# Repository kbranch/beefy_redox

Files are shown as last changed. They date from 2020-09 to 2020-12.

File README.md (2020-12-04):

# Beefy Redox
This uses the Redox layout with significant modifications to make it feel and sound sturdy.  It's dumb and overkill, but I like it.  PCB has been redone to work with Kailh MX hotswap sockets because Mill-Max sockets don't really fit some switches (like Kailh's box series).

Based on Mattia Dal Ben's Redox keyboard: https://github.com/mattdibi/redox-keyboard

Case based on Fosk_LL's design: https://www.thingiverse.com/thing:3607303

Associated hacked together firmware: https://github.com/kbranch/qmk_beefy_redox

Disasterous CAD files are available here:
https://cad.onshape.com/documents/79753b5942c6535c2d806763/w/4c8392e04a1d78f77636699a/e/d620deb7dfbc2bdc09fda4c7
https://cad.onshape.com/documents/7a9b7e869b26a13f2521e861/w/94ad519ba1de32380f27d44b/e/4a5e31582eda700c8368bdb9

## Printing

The STLs folder here on GitHub should include everything you need.  Some portions of the case are symmetrical, while others are not.  If there is no "Right" version of a model that has a "Left" version, use your slicer to mirror the left version to create the right version.

I used PrusaSlicer with my non-MMU printer to print the little LED diffuser bits in white by setting it up to let me manually change the filament at the right time, but you can also print the diffusers separately and install them after the fact.  The STLs folder has the separate plug as well as individual models suitable for importing as part of a multi-material file.

## Assembly

This is designed to use a separate plate for the switches - the "Redox_Plate.dxf" file should be suitable for sending to a company to be laser cut, although you will likely need to drill the M2 holes out to size.  I found stainless steel to sound best, but any other 1.5 mm thick material should also work.  The plate can be attached to the case with six M2 screws. I found that the sound improved when I offset the plate from the case with a little o-ring around each screw, but that's optional.

The case halves are designed to be held together with M3 screws.  There are pockets for M3 nuts - you may need to glue the nuts in place, the pockets are tricky to print well.

Note that the footprint for the microcontroller is wider than a Pro Micro due to PCB space limitations after turning the switch footprint into swiss cheese.  I floated a header off to the side of my Pro Micros with a bunch of fine wire to make it fit.

This uses four panel mount USB-C connectors - one for each controller, and one on each side for the connection between the two halves.  I used these, but there may be other places to get some with the same dimensions: https://www.adafruit.com/product/4053

The LED PCB uses these LEDs, 9 per side: https://www.adafruit.com/product/3484

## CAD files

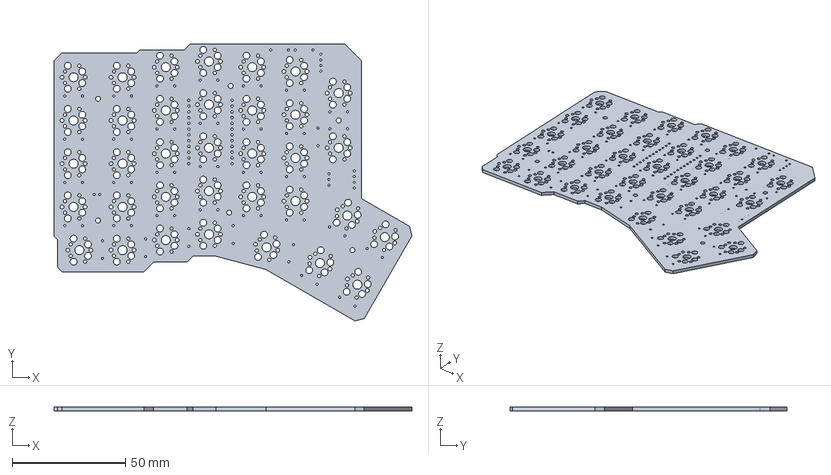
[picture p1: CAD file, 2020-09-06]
kicad_files/redox_rev1.1-kb.step
157.8 x 122.0 x 1.60 mm

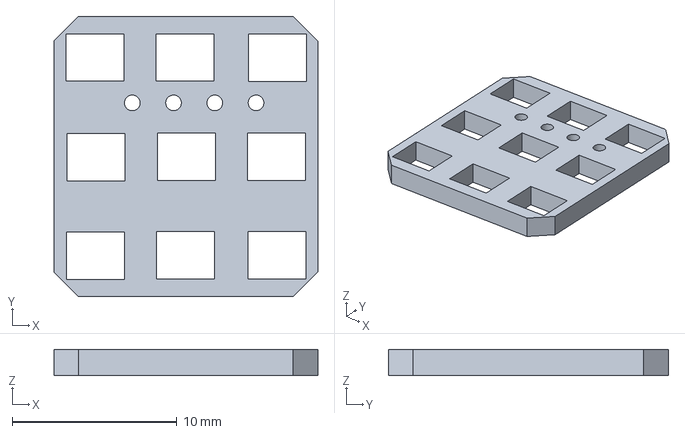
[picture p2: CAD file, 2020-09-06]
kicad_files/status_leds/status_leds/status_leds.step
16.0 x 17.0 x 1.60 mm

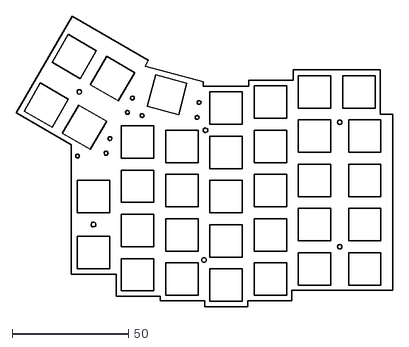
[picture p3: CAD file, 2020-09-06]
Redox_Plate.dxf
161.9 x 125.0

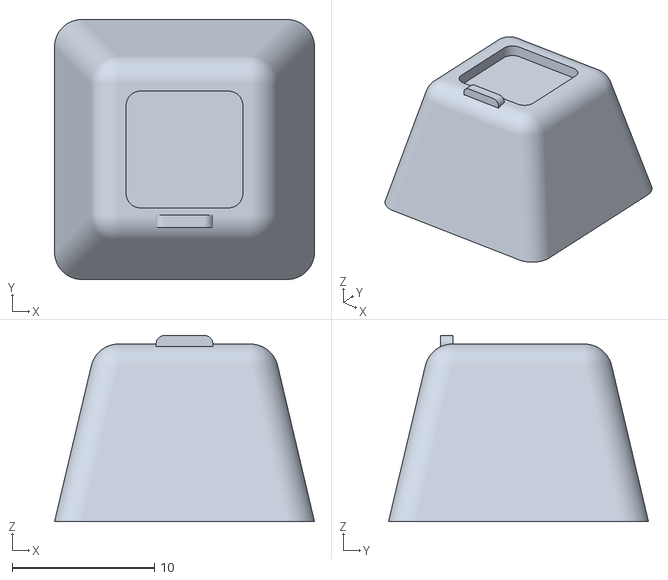
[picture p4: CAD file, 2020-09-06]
STLs/Keycaps/Keycap - 1U R3 Bump.stl
18.3 x 18.3 x 13.1

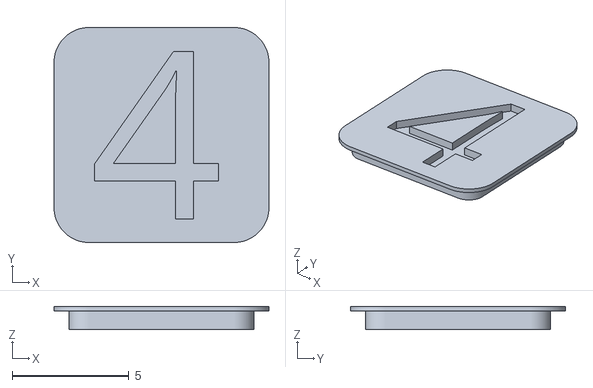
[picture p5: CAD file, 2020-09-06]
STLs/Keycaps/Legends/Keycap - Legend Block - 4.stl
9.21 x 9.21 x 1.00

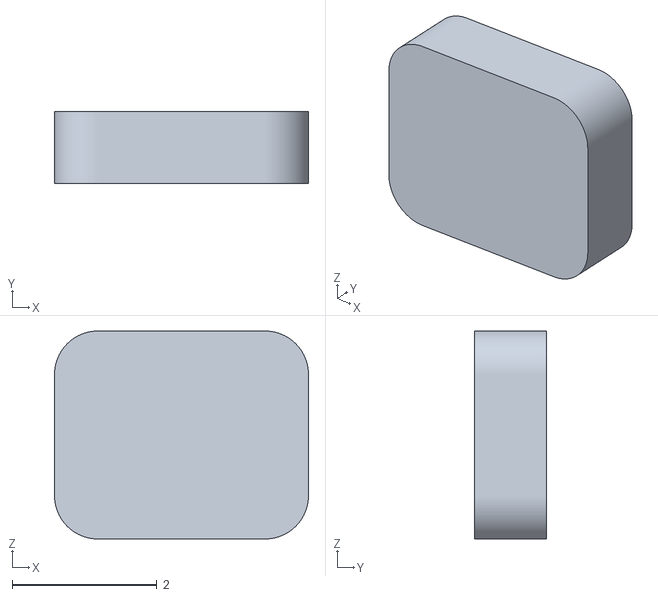
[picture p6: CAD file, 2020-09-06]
STLs/Left Top (mirror for right)/Integrated LED Plug 6.stl
3.51 x 1.00 x 2.87

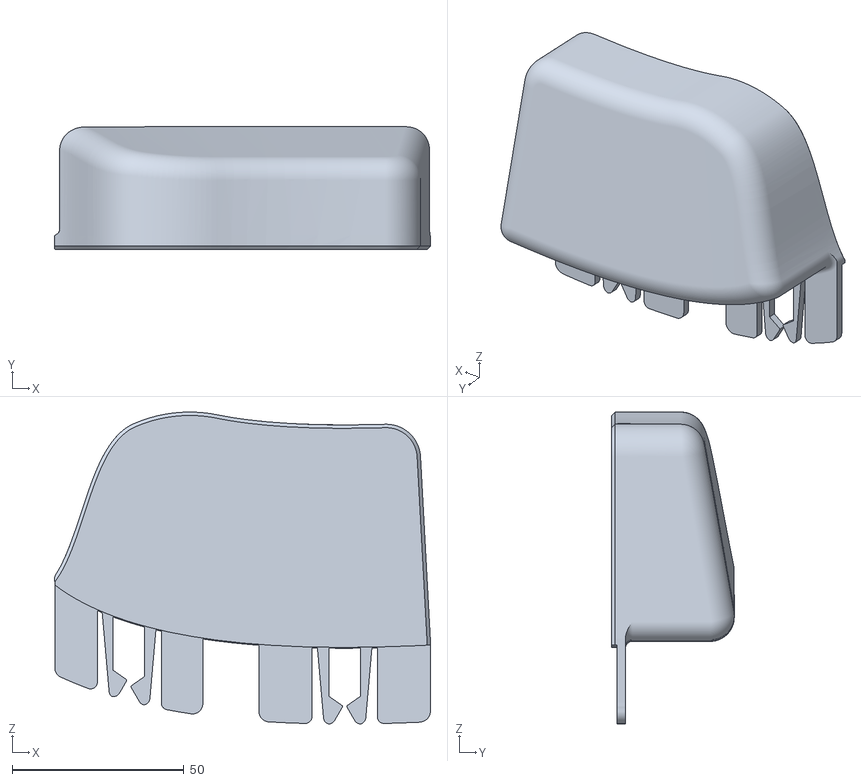
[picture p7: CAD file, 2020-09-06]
STLs/Right Wrist Rest.stl
109.4 x 35.7 x 90.8

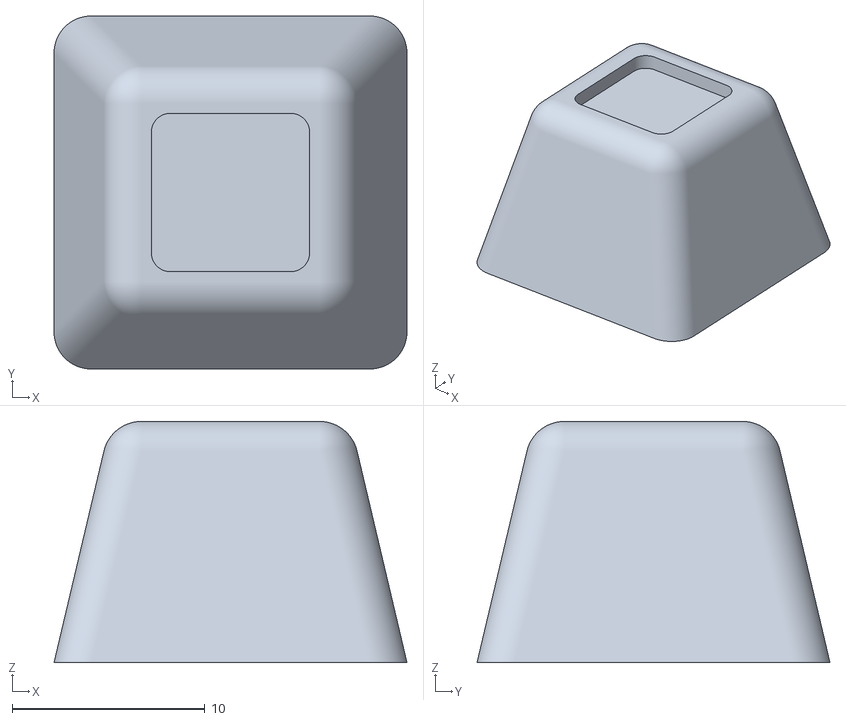
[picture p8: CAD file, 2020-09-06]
STLs/Keycaps/Keycap - 1U R3.stl
18.3 x 18.3 x 12.5

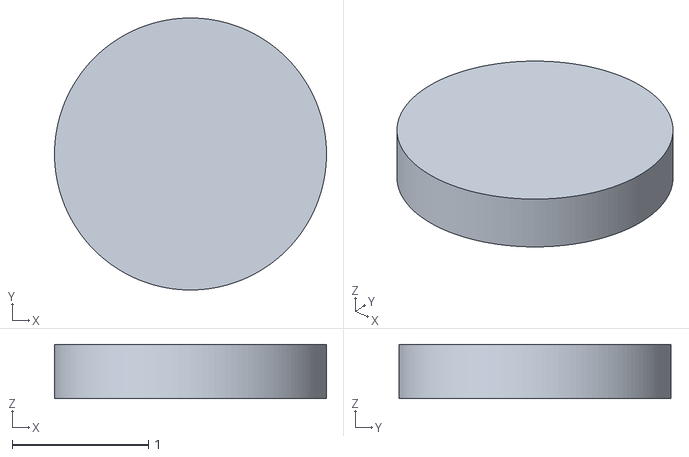
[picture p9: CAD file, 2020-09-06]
STLs/Keycaps/Legends/Keycap - Part 4 - 3 dots.stl
2.00 x 2.00 x 0.4

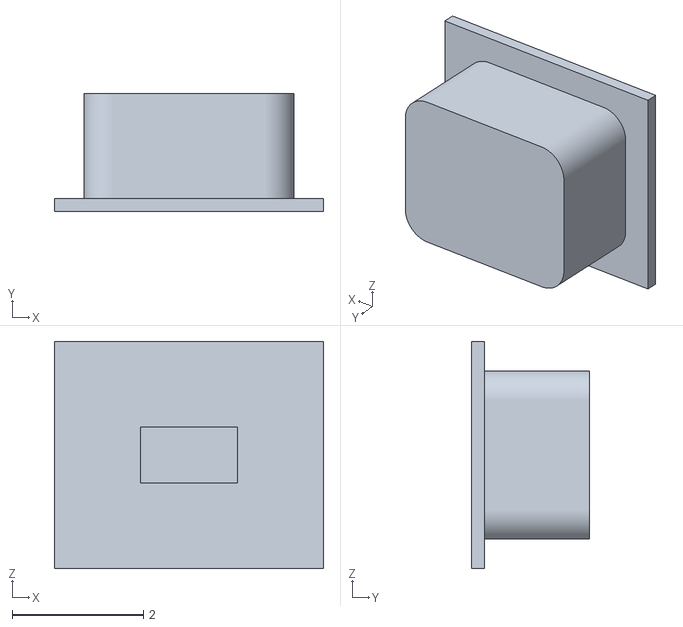
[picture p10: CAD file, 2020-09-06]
STLs/Left Top (mirror for right)/Separate LED Plug.stl
4.11 x 1.80 x 3.47

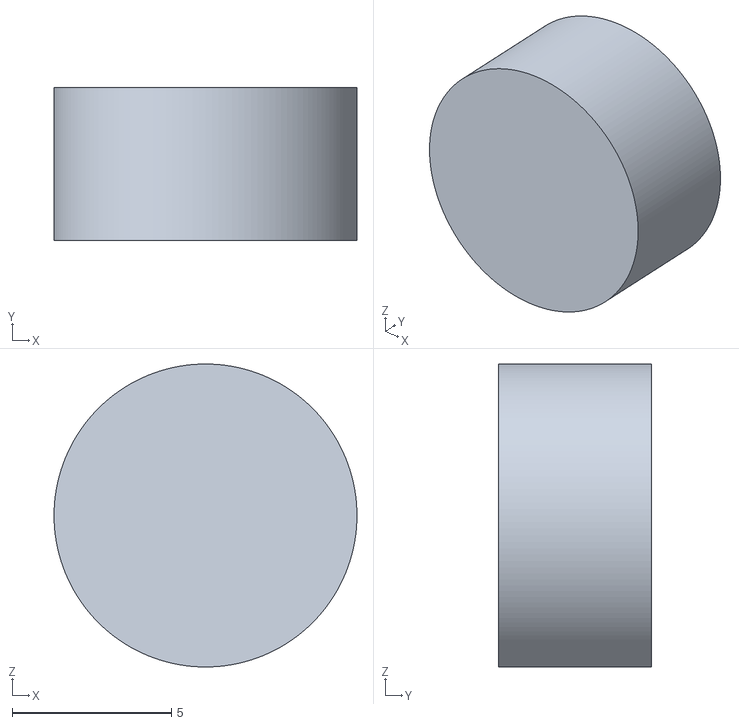
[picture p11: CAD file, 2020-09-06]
STLs/Button.stl
9.50 x 4.80 x 9.50

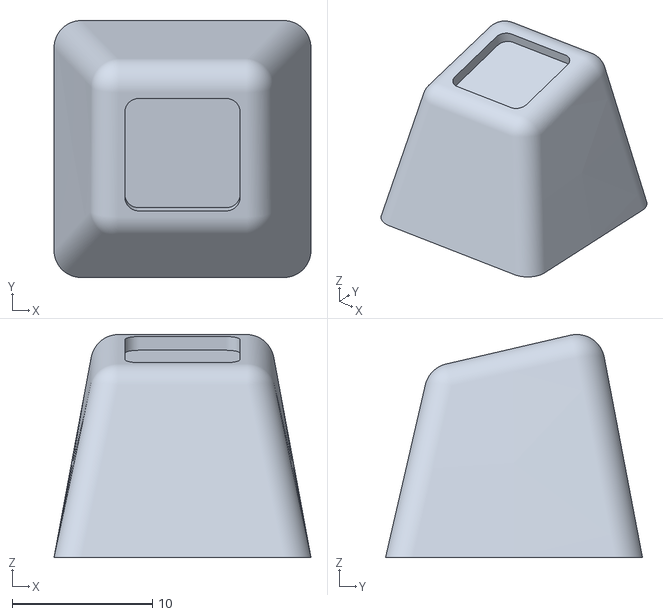
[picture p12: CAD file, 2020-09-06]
STLs/Keycaps/Keycap - 1U R1.stl
18.3 x 18.3 x 15.9

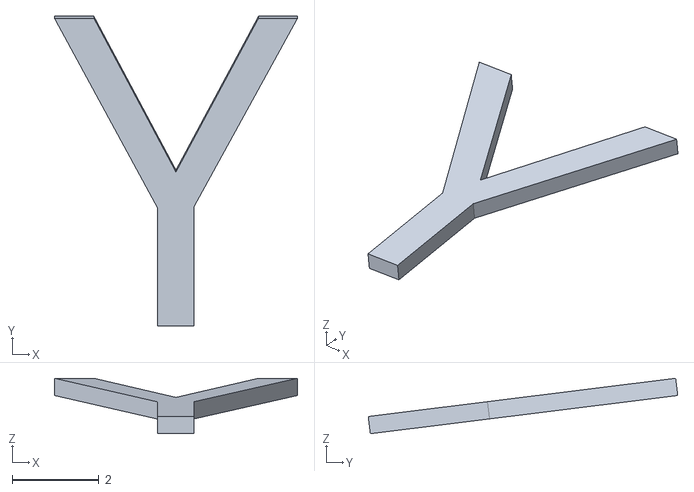
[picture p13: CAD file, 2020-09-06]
STLs/Keycaps/Legends/Keycap - Legend - Y.stl
5.61 x 7.15 x 1.28

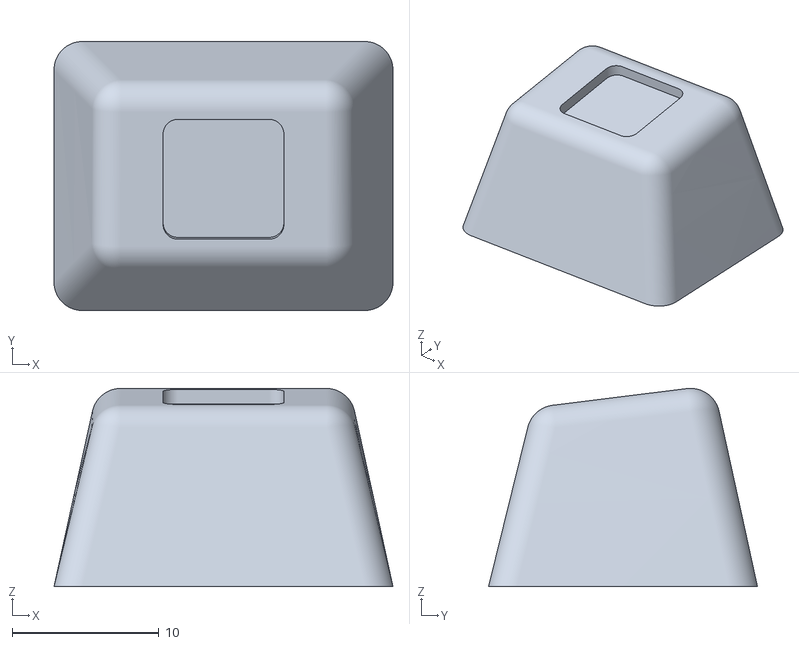
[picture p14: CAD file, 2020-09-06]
STLs/Keycaps/Keycap - 1.25U R2.stl
23.1 x 18.3 x 13.5

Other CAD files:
STLs/Left Wrist Rest.stl
STLs/Left Top (mirror for right)/Integrated LED Plug 3.stl
STLs/Keycaps/Legends/Keycap - Legend Block - Circle.stl
STLs/LED Retainer.stl
STLs/Button Holder.stl
STLs/Keycaps/Keycap - 1.25U R1.stl
STLs/Keycaps/Keycap - 1.25U R3.stl
STLs/Keycaps/Keycap - 1.25U R4.stl
STLs/Keycaps/Keycap - 1.5U R3.stl
STLs/Keycaps/Keycap - 1U R2.stl
STLs/Keycaps/Keycap - 1U R4.stl
STLs/Keycaps/Legends/Keycap - Legend - '-(1).stl
STLs/Keycaps/Legends/Keycap - Legend - '-(2).stl
STLs/Keycaps/Legends/Keycap - Legend - '-.stl
STLs/Keycaps/Legends/Keycap - Legend - ,.stl
STLs/Keycaps/Legends/Keycap - Legend - -.stl
STLs/Keycaps/Legends/Keycap - Legend - ..stl
STLs/Keycaps/Legends/Keycap - Legend - 0.stl
STLs/Keycaps/Legends/Keycap - Legend - 1.stl
STLs/Keycaps/Legends/Keycap - Legend - 2.stl
STLs/Keycaps/Legends/Keycap - Legend - 3.stl
STLs/Keycaps/Legends/Keycap - Legend - 4.stl
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

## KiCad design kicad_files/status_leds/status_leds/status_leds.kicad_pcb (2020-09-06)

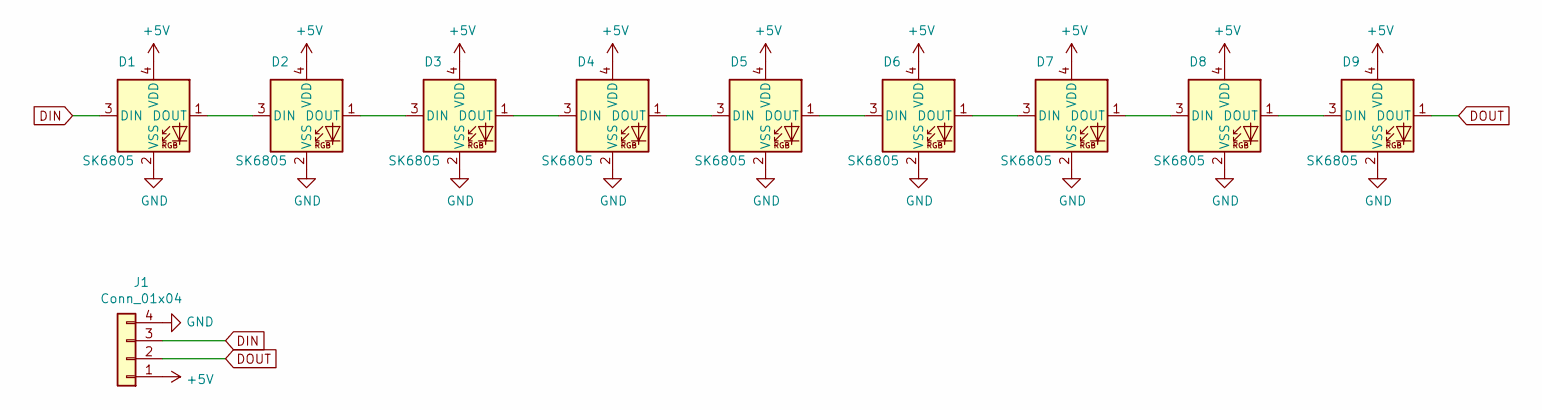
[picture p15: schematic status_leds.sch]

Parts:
D1, D2, D3, D4, D5, D6, D7, D8, D9: SK6805; LED_SK6805_PLCC4_2.4x2.7mm_P1.3mm
J1: Conn_01x04; JST_XH_B4B-XH-A_1x04_P2.50mm_Vertical

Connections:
+5V: D1.4 (VDD), D2.4 (VDD), D3.4 (VDD), D4.4 (VDD), D5.4 (VDD), D6.4 (VDD), D7.4 (VDD), D8.4 (VDD), D9.4 (VDD), J1.1
DIN: D1.3 (DIN), J1.3
DOUT: D9.1 (DOUT), J1.2
GND: D1.2 (VSS), D2.2 (VSS), D3.2 (VSS), D4.2 (VSS), D5.2 (VSS), D6.2 (VSS), D7.2 (VSS), D8.2 (VSS), D9.2 (VSS), J1.4
unnamed: D1.1 (DOUT), D2.3 (DIN)
unnamed: D2.1 (DOUT), D3.3 (DIN)
unnamed: D3.1 (DOUT), D4.3 (DIN)
unnamed: D4.1 (DOUT), D5.3 (DIN)
unnamed: D5.1 (DOUT), D6.3 (DIN)
unnamed: D6.1 (DOUT), D7.3 (DIN)
unnamed: D7.1 (DOUT), D8.3 (DIN)
unnamed: D8.1 (DOUT), D9.3 (DIN)

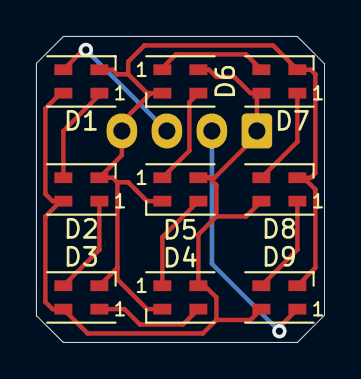
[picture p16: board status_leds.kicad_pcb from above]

Board: 2 copper layers, 16.0 x 17.0 mm, 10 parts (1 on the bottom side), 12 nets.

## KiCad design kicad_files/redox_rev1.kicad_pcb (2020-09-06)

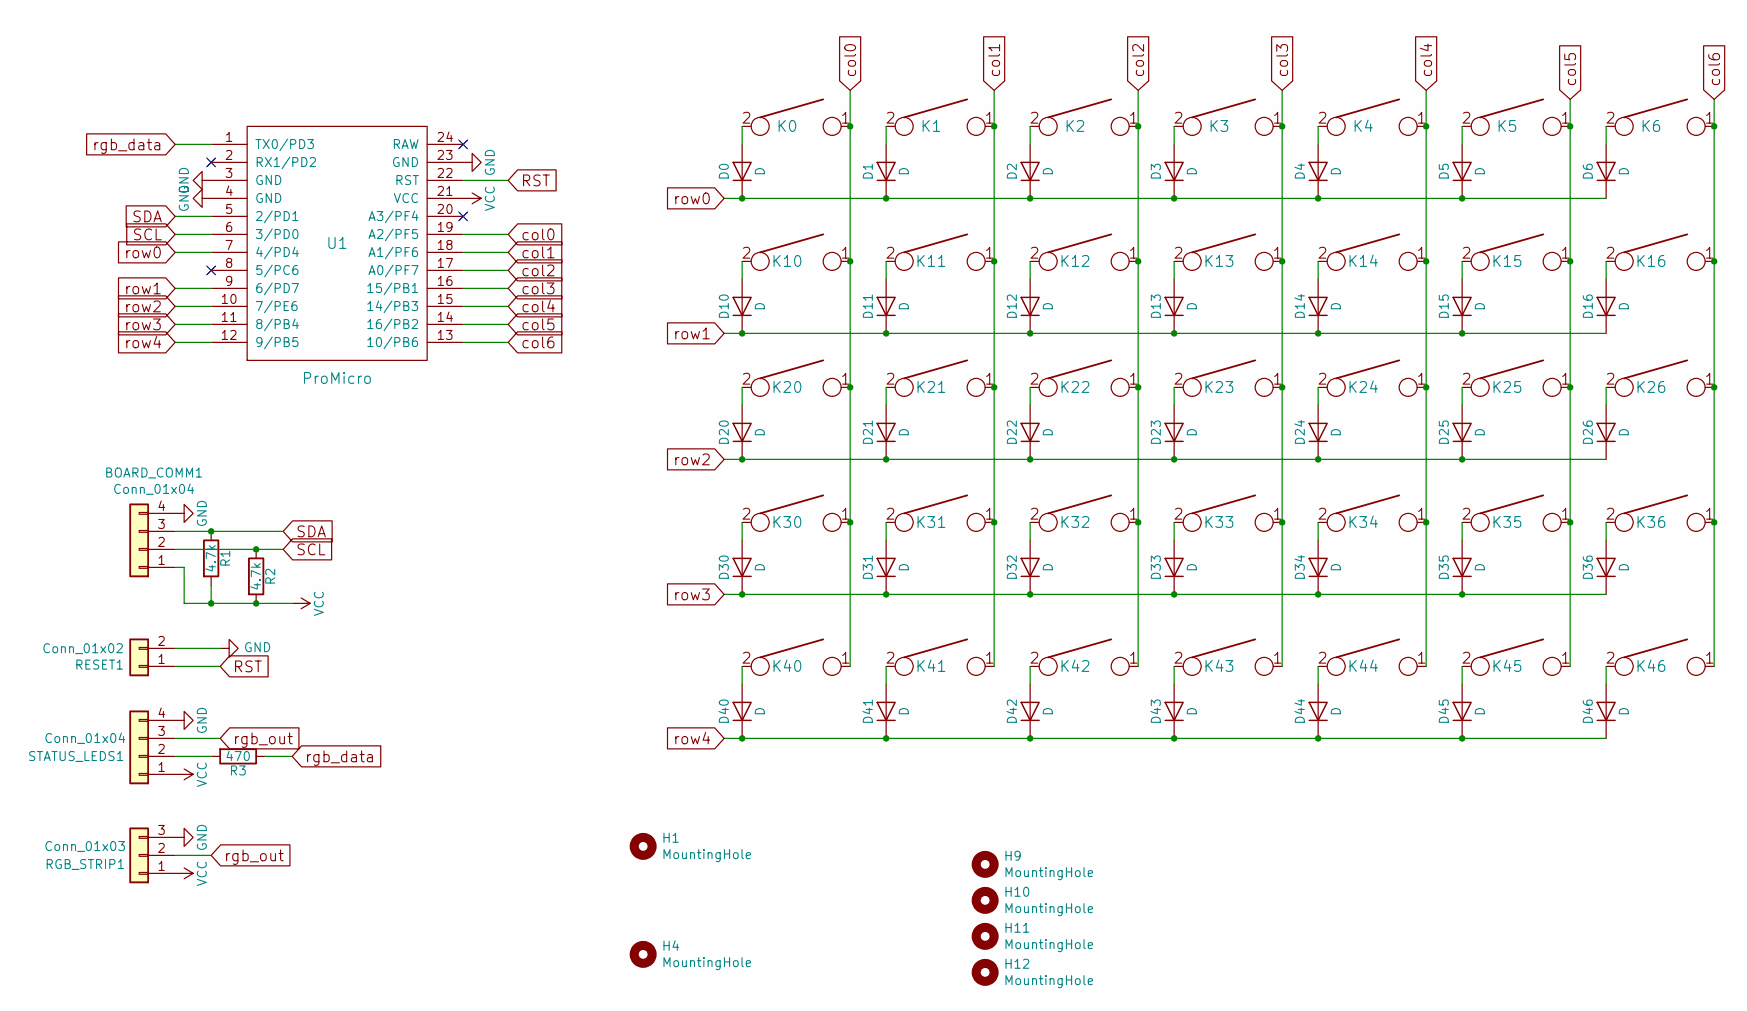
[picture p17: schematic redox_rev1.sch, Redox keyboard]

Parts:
BOARD_COMM1: Conn_01x04; JST_XH_S4B-XH-A_1x04_P2.50mm_Horizontal
D0, D1, D2, D3, D4, D5, D6, D10, D11, D12, D13, D14, D15, D16, D20, D21, D22, D23, D24, D25, D26, D30, D31, D32, D33, D34, D35, D36, D40, D41, D42, D43, D44, D45, D46: D; Diode-dual
H1, H4, H9, H10, H11, H12: MountingHole; MountingHole_2.2mm_M2
K0, K1, K2, K3, K4, K5, K6, K10, K11, K12, K13, K14, K15, K16, K20, K21, K22, K23, K24, K25, K26, K30, K31, K32, K33, K34, K35, K36, K40, K41, K42, K43, K44, K45, K46: KEYSW; Kailh_socket_MX_optional_reversible
R1, R2: 4.7k; Resistor-Compact
R3: 470; Resistor-Compact
RESET1: Conn_01x02; JST_XH_S2B-XH-A_1x02_P2.50mm_Horizontal
RGB_STRIP1: Conn_01x03; JST_XH_S3B-XH-A_1x03_P2.50mm_Horizontal
STATUS_LEDS1: Conn_01x04; JST_XH_S4B-XH-A_1x04_P2.50mm_Horizontal
U1: ProMicro; ArduinoProMicro-Wide

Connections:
GND: BOARD_COMM1.4, RESET1.2, RGB_STRIP1.3, STATUS_LEDS1.4, U1.3 (GND), U1.4 (GND), U1.23 (GND)
unnamed: D0.2 (A), K0.2
unnamed: D1.2 (A), K1.2
unnamed: D2.2 (A), K2.2
unnamed: D3.2 (A), K3.2
unnamed: D4.2 (A), K4.2
unnamed: D5.2 (A), K5.2
unnamed: D6.2 (A), K6.2
unnamed: D10.2 (A), K10.2
unnamed: D11.2 (A), K11.2
unnamed: D12.2 (A), K12.2
unnamed: D13.2 (A), K13.2
unnamed: D14.2 (A), K14.2
unnamed: D15.2 (A), K15.2
unnamed: D16.2 (A), K16.2
unnamed: D20.2 (A), K20.2
unnamed: D21.2 (A), K21.2
unnamed: D22.2 (A), K22.2
unnamed: D23.2 (A), K23.2
unnamed: D24.2 (A), K24.2
unnamed: D25.2 (A), K25.2
unnamed: D26.2 (A), K26.2
unnamed: D30.2 (A), K30.2
unnamed: D31.2 (A), K31.2
unnamed: D32.2 (A), K32.2
unnamed: D33.2 (A), K33.2
unnamed: D34.2 (A), K34.2
unnamed: D35.2 (A), K35.2
unnamed: D36.2 (A), K36.2
unnamed: D40.2 (A), K40.2
unnamed: D41.2 (A), K41.2
unnamed: D42.2 (A), K42.2
unnamed: D43.2 (A), K43.2
unnamed: D44.2 (A), K44.2
unnamed: D45.2 (A), K45.2
unnamed: D46.2 (A), K46.2
unnamed: R3.2, STATUS_LEDS1.2
RST: RESET1.1, U1.22 (RST)
SCL: BOARD_COMM1.2, R2.1, U1.6 (3/PD0)
SDA: BOARD_COMM1.3, R1.1, U1.5 (2/PD1)
VCC: BOARD_COMM1.1, R1.2, R2.2, RGB_STRIP1.1, STATUS_LEDS1.1, U1.21 (VCC)
col0: K0.1, K10.1, K20.1, K30.1, K40.1, U1.19 (A2/PF5)
col1: K1.1, K11.1, K21.1, K31.1, K41.1, U1.18 (A1/PF6)
col2: K2.1, K12.1, K22.1, K32.1, K42.1, U1.17 (A0/PF7)
col3: K3.1, K13.1, K23.1, K33.1, K43.1, U1.16 (15/PB1)
col4: K4.1, K14.1, K24.1, K34.1, K44.1, U1.15 (14/PB3)
col5: K5.1, K15.1, K25.1, K35.1, K45.1, U1.14 (16/PB2)
col6: K6.1, K16.1, K26.1, K36.1, K46.1, U1.13 (10/PB6)
rgb_data: R3.1, U1.1 (TX0/PD3)
rgb_out: RGB_STRIP1.2, STATUS_LEDS1.3
row0: D0.1 (K), D1.1 (K), D2.1 (K), D3.1 (K), D4.1 (K), D5.1 (K), D6.1 (K), U1.7 (4/PD4)
row1: D10.1 (K), D11.1 (K), D12.1 (K), D13.1 (K), D14.1 (K), D15.1 (K), D16.1 (K), U1.9 (6/PD7)
row2: D20.1 (K), D21.1 (K), D22.1 (K), D23.1 (K), D24.1 (K), D25.1 (K), D26.1 (K), U1.10 (7/PE6)
row3: D30.1 (K), D31.1 (K), D32.1 (K), D33.1 (K), D34.1 (K), D35.1 (K), D36.1 (K), U1.11 (8/PB4)
row4: D40.1 (K), D41.1 (K), D42.1 (K), D43.1 (K), D44.1 (K), D45.1 (K), D46.1 (K), U1.12 (9/PB5)

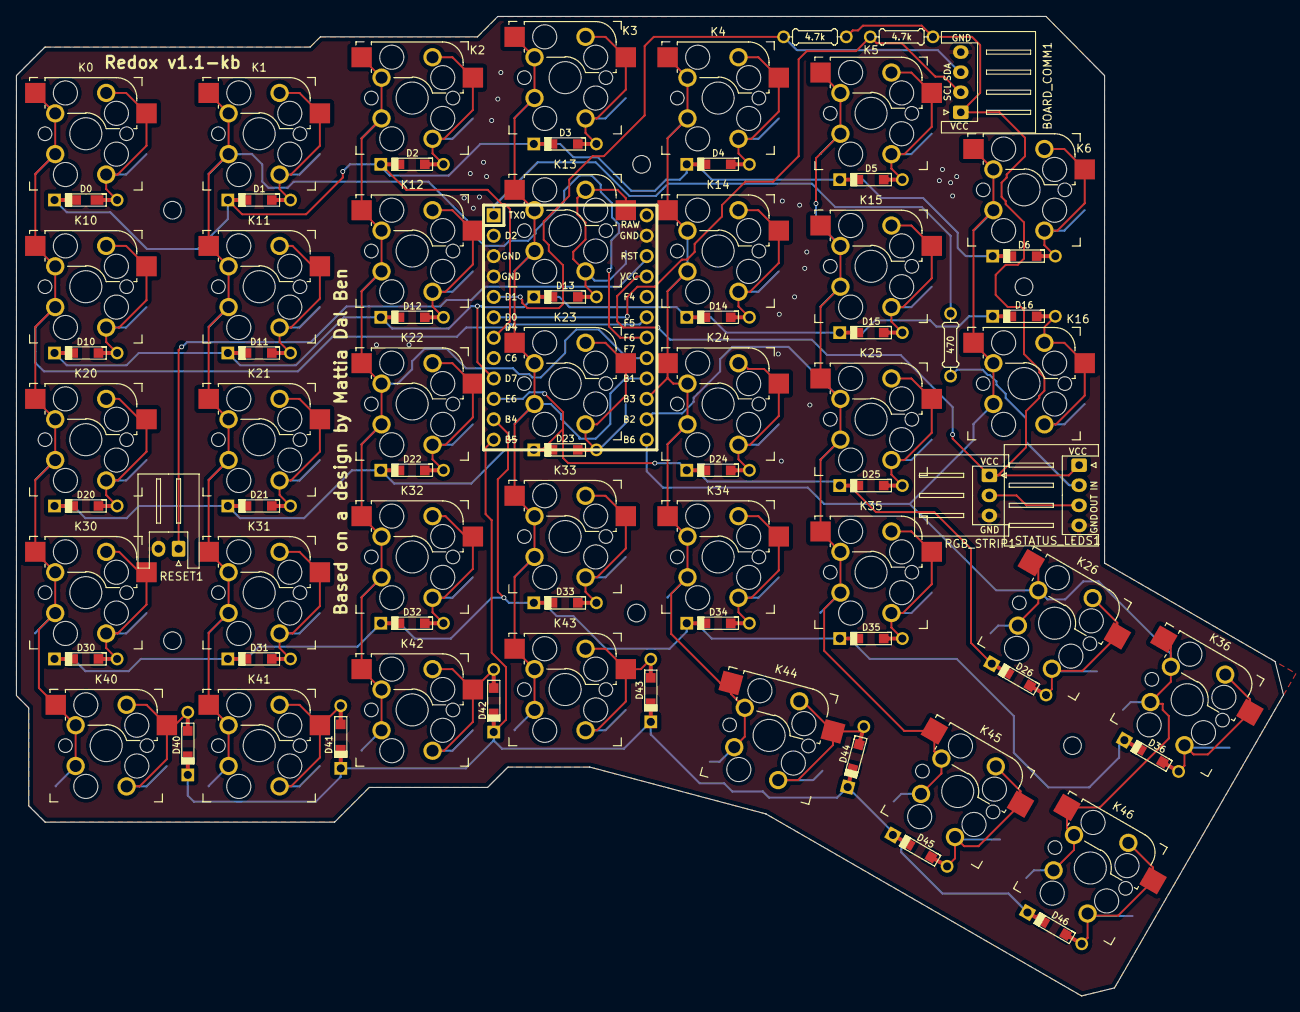
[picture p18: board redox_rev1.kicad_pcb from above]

Board: 2 copper layers, 157.8 x 122.0 mm, 84 parts (0 on the bottom side), 55 nets.
